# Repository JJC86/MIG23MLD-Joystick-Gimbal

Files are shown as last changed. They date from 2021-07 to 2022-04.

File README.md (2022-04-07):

# MIG23MLD Flight Stick Clone

Gallery :<br>
(Old version) : https://imgur.com/gallery/pQZL5Sh

## Before starting
Currently grip & button design is prototype. It is too hard to assemble, no trigger group.... <br>
And also it is not 100% replica of Mig23MLD flight stick. My laziness + lack of cad skill lead to 80% clone of original.<br>
Will be improved soon!

## Credits
Based on okulele's gimbal design : https://www.thingiverse.com/thing:2496028 <br>
Used rdbeerman's cad files : https://github.com/rdbeerman/Joystick-Gimbal <br>
Used Murat Vishnyakov's KG13 Grip cad file : https://grabcad.com/library/kg-13-flight-control-grip-1 <br>
Referenced GGE2142's Mig23 Flight stick's 3d design : https://sketchfab.com/3d-models/mig-23mld-flight-stick-855707656b494a63adcc3c0fc8ba19b1 <br>

## How to assemble this thing?
Full Assembly will look like this
CAD : https://cad.onshape.com/documents/d2949292de745de5f3a0b3dc/w/86e25e9ccd34e276e2b01614/e/ad812c8cff31ec84eae2079d

BoM & Notes:<br>
dimension is slightly different from original design. Just because I used cheaper & available one. 
Also used sleeve bearings on cams for lower cost.

- Bearing 6901zz * 4
- Bearing MR115zz * 4
- Sleeve Bearing GFM-0507-11 * 4
- Sleeve Bearing GFM-0709-10 * 4
- M3x16 cross head/hex bolt * 1
- M3 Nut * 1
- M5x25 cross head/hex bolt * 20
- M5x35 countersunk/hex bolt * 3
- M5x16 countersunk/hex bolt * 2
- M5x35 cross head/hex bolt * 11
- M5 spring washer * 10
- M5 nut * 36
- M3x6 cross head/hex bolt * 6 (optional) 
<br>

Buttons
- [PS1024ALRED](https://github.com/tiktrimo/MIG23MLD-Joystick-Gimbal/blob/main/images/20210718_0329.png) * 1 (Push button)
- [TH101010](https://github.com/tiktrimo/MIG23MLD-Joystick-Gimbal/blob/main/images/Image%20001.png) * 2 (5 Way button)
- [NW3-TS-G008](https://github.com/tiktrimo/MIG23MLD-Joystick-Gimbal/blob/main/images/Image%20002.png) * 1 (Tact switch)
<br>
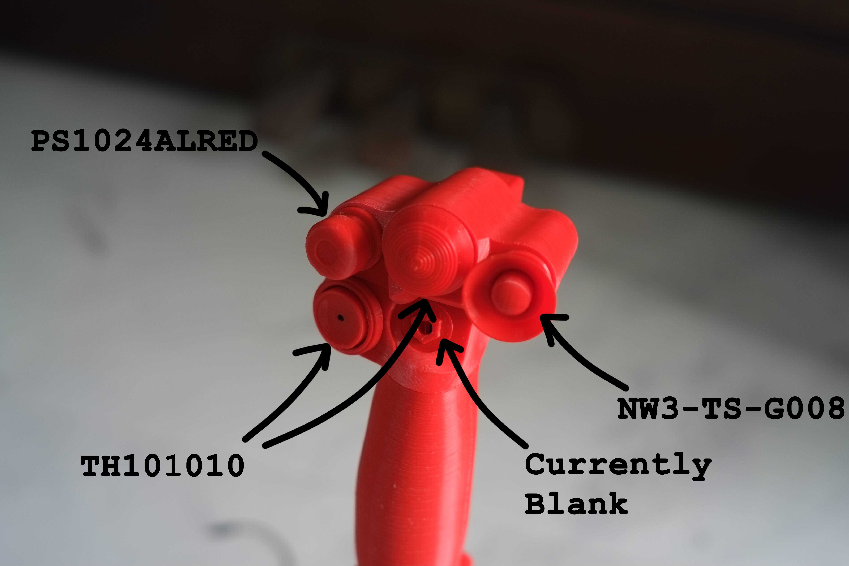
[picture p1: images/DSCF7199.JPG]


Used WSH135-XPAN2 Hall effect sensor. This was cheapest in store and cost about 50 cent. With 4x4x10mm neodymium magnet it gives 500 steps on each axis.

## Recommendation
I recommend to change gap between buttons and head. Currently gap is set to 0.15mm. For my printer 0.15mm gap gives me perfect fit with click! sound. 

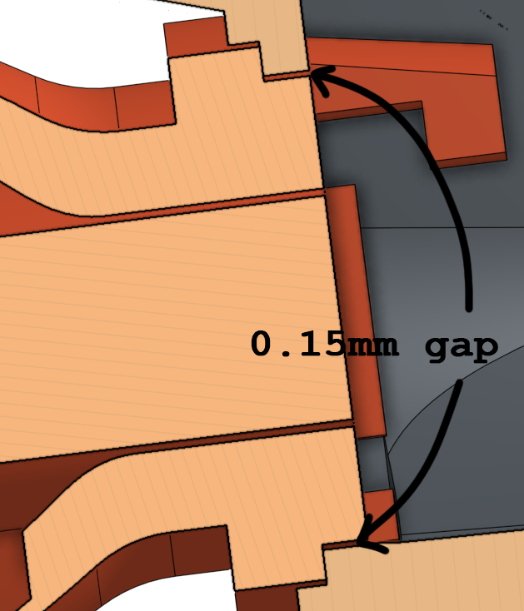
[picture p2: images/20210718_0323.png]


## Issues
Feel free to [Issue](https://github.com/tiktrimo/MIG23MLD-Joystick-Gimbal/issues) any subject (e.g broken english, need more explaining...).

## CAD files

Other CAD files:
Gimbal/Extra/Gimbal - Core Hall Effect Seonsor Holder.x_t
Gimbal/Extra/Gimbal - Frame Hall Effect Sensor Holder.x_t
Gimbal/Extra/Gimbal - Magnet Holder.x_t
Gimbal/Gimbal - Cam.x_t
Gimbal/Gimbal - Core Bearing Carrier Cam Side.x_t
Gimbal/Gimbal - Core Bearing Carrier Pot Side.x_t
Gimbal/Gimbal - Core Cam Side.x_t
Gimbal/Gimbal - Core Pot Side.x_t
Gimbal/Gimbal - Frame Cam Side.x_t
Gimbal/Gimbal - Frame Pot Side.x_t
Gimbal/Gimbal - Lever Arm.x_t
Housing/Housing - Base.x_t
Housing/Housing - Cap.x_t
Housing/Housing - Legs.x_t
Joystick/Joystick - Cup Button Cap.x_t
Joystick/Joystick - Cupbutton Base.x_t
Joystick/Joystick - Grip Base.x_t
Joystick/Joystick - Hat Button Base.x_t
Joystick/Joystick - Hat Button Cap.x_t
Joystick/Joystick - Head Cap.x_t
Joystick/Joystick - Head.x_t
Joystick/Joystick - Hex Button Base.x_t
Joystick/Joystick - Red Button Base.x_t
Joystick/Joystick - Red Button Cap.x_t
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
